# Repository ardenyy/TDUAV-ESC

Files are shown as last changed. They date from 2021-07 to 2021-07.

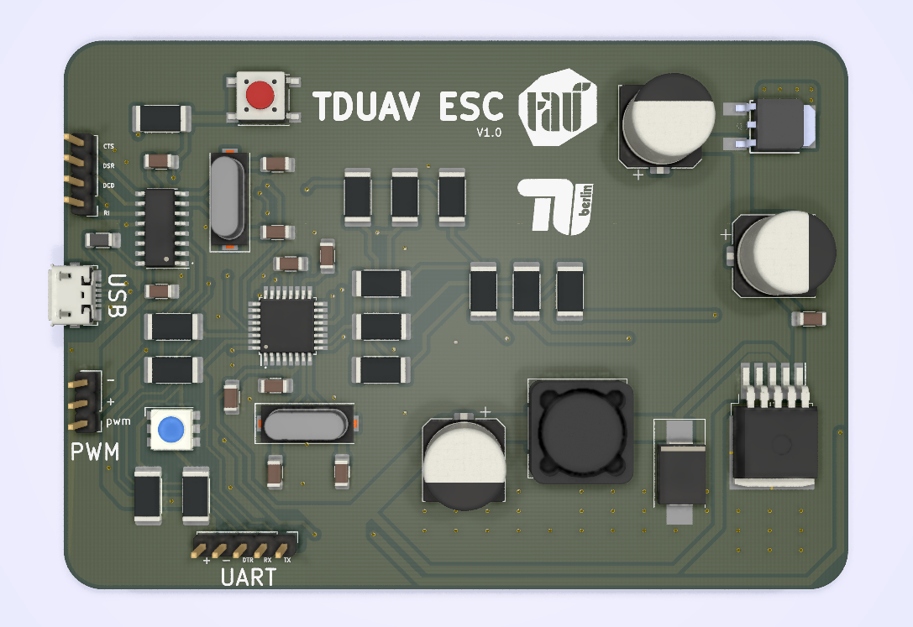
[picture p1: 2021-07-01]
Hardware/pcb_front.png

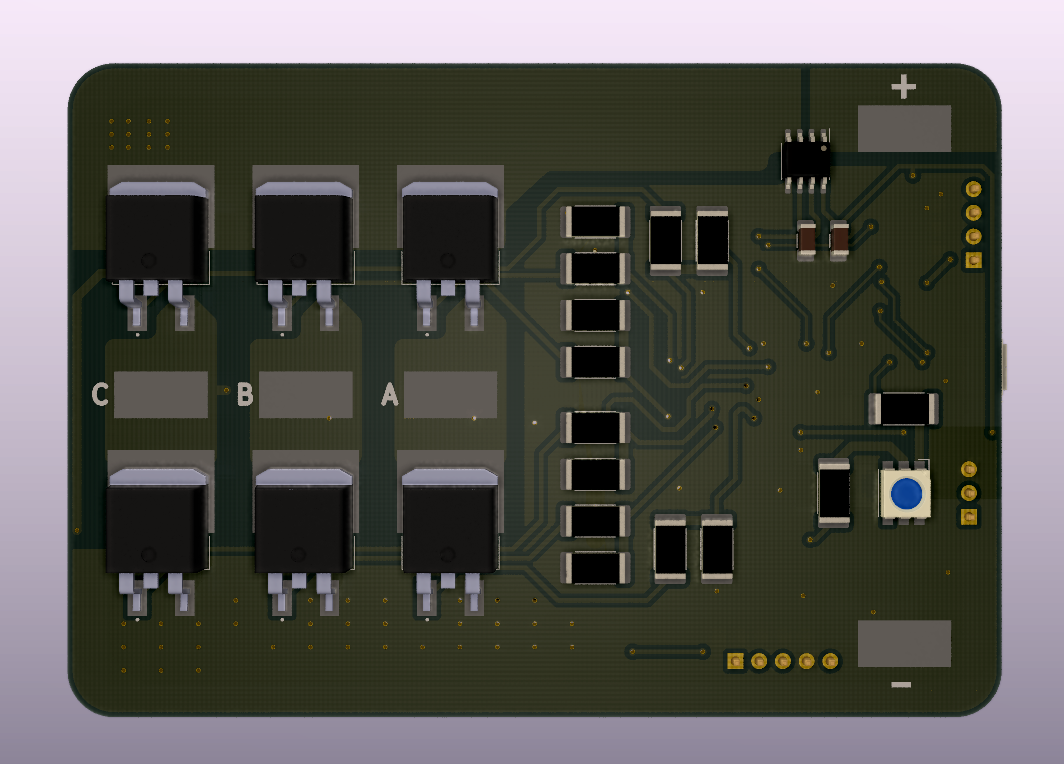
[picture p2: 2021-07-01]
Hardware/pcb_back.png

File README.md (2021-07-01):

# TDUAV-ESC
Electronic Speed Controller for BLDC Motors with 3A UBEC.

Made for UAV Team "**TDUAV**" at Turkish-German University.
- Atmega328P-AU Microcontroller
- Designed for 3S Li-Po Batteries
- BEMF Detection
- 5V/3A UBEC Circuit
- Up to 50A current sensing
- 35A Continuous, 50A Burst current output
- 100mm x 70mm

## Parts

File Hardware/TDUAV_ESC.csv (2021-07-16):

Source: | C:\Users\Ardeny\Documents\KiCAD\TDUAV_ESC\Hardware\TDUAV_ESC.sch
Date: | 17.07.2021 00:18:31
Tool: | Eeschema (5.1.9)-1
Component Count: | 73
Ref | Value | Footprint | Datasheet | Manufacturer | Vendor
C1 | 470uF | Capacitor_SMD:CP_Elec_10x10 | ~
C2 | 220uF | Capacitor_SMD:CP_Elec_10x10 | ~
C3 | 680nF | Capacitor_SMD:C_1206_3216Metric_Pad1.33x1.80mm_HandSolder | ~
C4 | 100nF | Capacitor_SMD:C_1206_3216Metric_Pad1.33x1.80mm_HandSolder | ~
C5 | 1nF | Capacitor_SMD:C_1206_3216Metric_Pad1.33x1.80mm_HandSolder | ~
C6 | 100nF | Capacitor_SMD:C_1206_3216Metric_Pad1.33x1.80mm_HandSolder | ~
C7 | 100nF | Capacitor_SMD:C_1206_3216Metric_Pad1.33x1.80mm_HandSolder | ~
C8 | 100nF | Capacitor_SMD:C_1206_3216Metric_Pad1.33x1.80mm_HandSolder | ~
C9 | 100nF | Capacitor_SMD:C_1206_3216Metric_Pad1.33x1.80mm_HandSolder | ~
C10 | 100nF | Capacitor_SMD:C_1206_3216Metric_Pad1.33x1.80mm_HandSolder | ~
C11 | 22pF | Capacitor_SMD:C_1206_3216Metric_Pad1.33x1.80mm_HandSolder | ~
C12 | 22pF | Capacitor_SMD:C_1206_3216Metric_Pad1.33x1.80mm_HandSolder | ~
C13 | 22pF | Capacitor_SMD:C_1206_3216Metric_Pad1.33x1.80mm_HandSolder | ~
C14 | 22pF | Capacitor_SMD:C_1206_3216Metric_Pad1.33x1.80mm_HandSolder | ~
C15 | 100nF | Capacitor_SMD:C_1206_3216Metric_Pad1.33x1.80mm_HandSolder | ~
C16 | 330uF | Capacitor_SMD:CP_Elec_10x10 | ~
C17 | 100nF | Capacitor_SMD:C_1206_3216Metric_Pad1.33x1.80mm_HandSolder | ~
D1 | SK56 | Diode_SMD:D_SMC_Handsoldering | ~
D2 | LED_RGB_5050 | LED_SMD:LED_RGB_5050-6
D3 | LED_RGB_5050 | LED_SMD:LED_RGB_5050-6
FB1 | 120R @ 100Mhz | Inductor_SMD:L_1206_3216Metric_Pad1.22x1.90mm_HandSolder | ~
J1 | USB_B_Micro | Connector_USB:USB_Micro-B_Molex_47346-0001 | ~
J2 | PWM-UBEC | Connector_PinHeader_2.54mm:PinHeader_1x03_P2.54mm_Vertical | ~
J3 | UART | Connector_PinHeader_2.54mm:PinHeader_1x05_P2.54mm_Vertical | ~
J4 | CH340 | Connector_PinHeader_2.54mm:PinHeader_1x04_P2.54mm_Vertical | ~
J5 | BATT | Connector_Wire:SolderWirePad_1x01_SMD_5x10mm | ~
J6 | GND | Connector_Wire:SolderWirePad_1x01_SMD_5x10mm | ~
J7 | PHASE_A | Connector_Wire:SolderWirePad_1x01_SMD_5x10mm | ~
J8 | PHASE_B | Connector_Wire:SolderWirePad_1x01_SMD_5x10mm | ~
J9 | PHASE_C | Connector_Wire:SolderWirePad_1x01_SMD_5x10mm | ~
L1 | 33uH | INDUCTOR_SMD:INDUCTOR_SMD_12X12X8 | ~
Q1 | IRLZ44NS | IRLZ44NSPBF:IRF2804STRLPBF | https://www.infineon.com/dgdl/irlz44nspbf.pdf?fileId=5546d462533600a40153567221272727
Q2 | IRLZ44NS | IRLZ44NSPBF:IRF2804STRLPBF | https://www.infineon.com/dgdl/irlz44nspbf.pdf?fileId=5546d462533600a40153567221272727
Q3 | IRFR9024 | IRFR9024:DPAK
Q4 | IRLZ44NS | IRLZ44NSPBF:IRF2804STRLPBF | https://www.infineon.com/dgdl/irlz44nspbf.pdf?fileId=5546d462533600a40153567221272727
Q5 | IRLZ44NS | IRLZ44NSPBF:IRF2804STRLPBF | https://www.infineon.com/dgdl/irlz44nspbf.pdf?fileId=5546d462533600a40153567221272727
Q6 | IRLZ44NS | IRLZ44NSPBF:IRF2804STRLPBF | https://www.infineon.com/dgdl/irlz44nspbf.pdf?fileId=5546d462533600a40153567221272727
Q7 | IRLZ44NS | IRLZ44NSPBF:IRF2804STRLPBF | https://www.infineon.com/dgdl/irlz44nspbf.pdf?fileId=5546d462533600a40153567221272727
R1 | 10KR | Resistor_SMD:R_2512_6332Metric_Pad1.40x3.35mm_HandSolder | ~
R2 | 1KR | Resistor_SMD:R_2512_6332Metric_Pad1.40x3.35mm_HandSolder | ~
R3 | 1KR | Resistor_SMD:R_2512_6332Metric_Pad1.40x3.35mm_HandSolder | ~
R4 | 1KR | Resistor_SMD:R_2512_6332Metric_Pad1.40x3.35mm_HandSolder | ~
R5 | 10KR | Resistor_SMD:R_2512_6332Metric_Pad1.40x3.35mm_HandSolder | ~
R6 | 1KR | Resistor_SMD:R_2512_6332Metric_Pad1.40x3.35mm_HandSolder | ~
R7 | 1KR | Resistor_SMD:R_2512_6332Metric_Pad1.40x3.35mm_HandSolder | ~
R8 | 150R | Resistor_SMD:R_2512_6332Metric_Pad1.40x3.35mm_HandSolder | ~
R9 | 2.2KR | Resistor_SMD:R_2512_6332Metric_Pad1.40x3.35mm_HandSolder | ~
R10 | 150R | Resistor_SMD:R_2512_6332Metric_Pad1.40x3.35mm_HandSolder | ~
R11 | 2.2KR | Resistor_SMD:R_2512_6332Metric_Pad1.40x3.35mm_HandSolder | ~
R12 | 33KR | Resistor_SMD:R_2512_6332Metric_Pad1.40x3.35mm_HandSolder | ~
R13 | 33KR | Resistor_SMD:R_2512_6332Metric_Pad1.40x3.35mm_HandSolder | ~
R14 | 33KR | Resistor_SMD:R_2512_6332Metric_Pad1.40x3.35mm_HandSolder | ~
R15 | 150R | Resistor_SMD:R_2512_6332Metric_Pad1.40x3.35mm_HandSolder | ~
R16 | 2.2KR | Resistor_SMD:R_2512_6332Metric_Pad1.40x3.35mm_HandSolder | ~
R17 | 150R | Resistor_SMD:R_2512_6332Metric_Pad1.40x3.35mm_HandSolder | ~
R18 | 2.2KR | Resistor_SMD:R_2512_6332Metric_Pad1.40x3.35mm_HandSolder | ~
R19 | 10KR | Resistor_SMD:R_2512_6332Metric_Pad1.40x3.35mm_HandSolder | ~
R20 | 10KR | Resistor_SMD:R_2512_6332Metric_Pad1.40x3.35mm_HandSolder | ~
R21 | 10KR | Resistor_SMD:R_2512_6332Metric_Pad1.40x3.35mm_HandSolder | ~
R22 | 33KR | Resistor_SMD:R_2512_6332Metric_Pad1.40x3.35mm_HandSolder | ~
R23 | 33KR | Resistor_SMD:R_2512_6332Metric_Pad1.40x3.35mm_HandSolder | ~
R24 | 33KR | Resistor_SMD:R_2512_6332Metric_Pad1.40x3.35mm_HandSolder | ~
R25 | 150R | Resistor_SMD:R_2512_6332Metric_Pad1.40x3.35mm_HandSolder | ~
R26 | 2.2KR | Resistor_SMD:R_2512_6332Metric_Pad1.40x3.35mm_HandSolder | ~
R27 | 150R | Resistor_SMD:R_2512_6332Metric_Pad1.40x3.35mm_HandSolder | ~
R28 | 2.2KR | Resistor_SMD:R_2512_6332Metric_Pad1.40x3.35mm_HandSolder | ~
SW1 | RESET_BUTTON | SW_PUSH_4:SW_PUSH_4_6X6mm_H3.1mm | ~
U1 | ATmega328P-AU | Package_QFP:TQFP-32_7x7mm_P0.8mm | http://ww1.microchip.com/downloads/en/DeviceDoc/ATmega328_P%20AVR%20MCU%20with%20picoPower%20Technology%20Data%20Sheet%2040001984A.pdf
U2 | ACS724-50A | Package_SO:SOIC-8_3.9x4.9mm_P1.27mm | http://www.allegromicro.com/~/media/Files/Datasheets/ACS724-Datasheet.ashx?la=en
U3 | LM2596S-5 | Package_TO_SOT_SMD:TO-263-5_TabPin3 | http://www.ti.com/lit/ds/symlink/lm2596.pdf
U4 | CH340G | Package_SO:SOIC-16_3.9x9.9mm_P1.27mm | http://www.datasheet5.com/pdf-local-2195953
Y1 | 16MHz | Crystal:Crystal_SMD_HC49-SD | ~
Y2 | 12MHz | Crystal:Crystal_SMD_HC49-SD | ~

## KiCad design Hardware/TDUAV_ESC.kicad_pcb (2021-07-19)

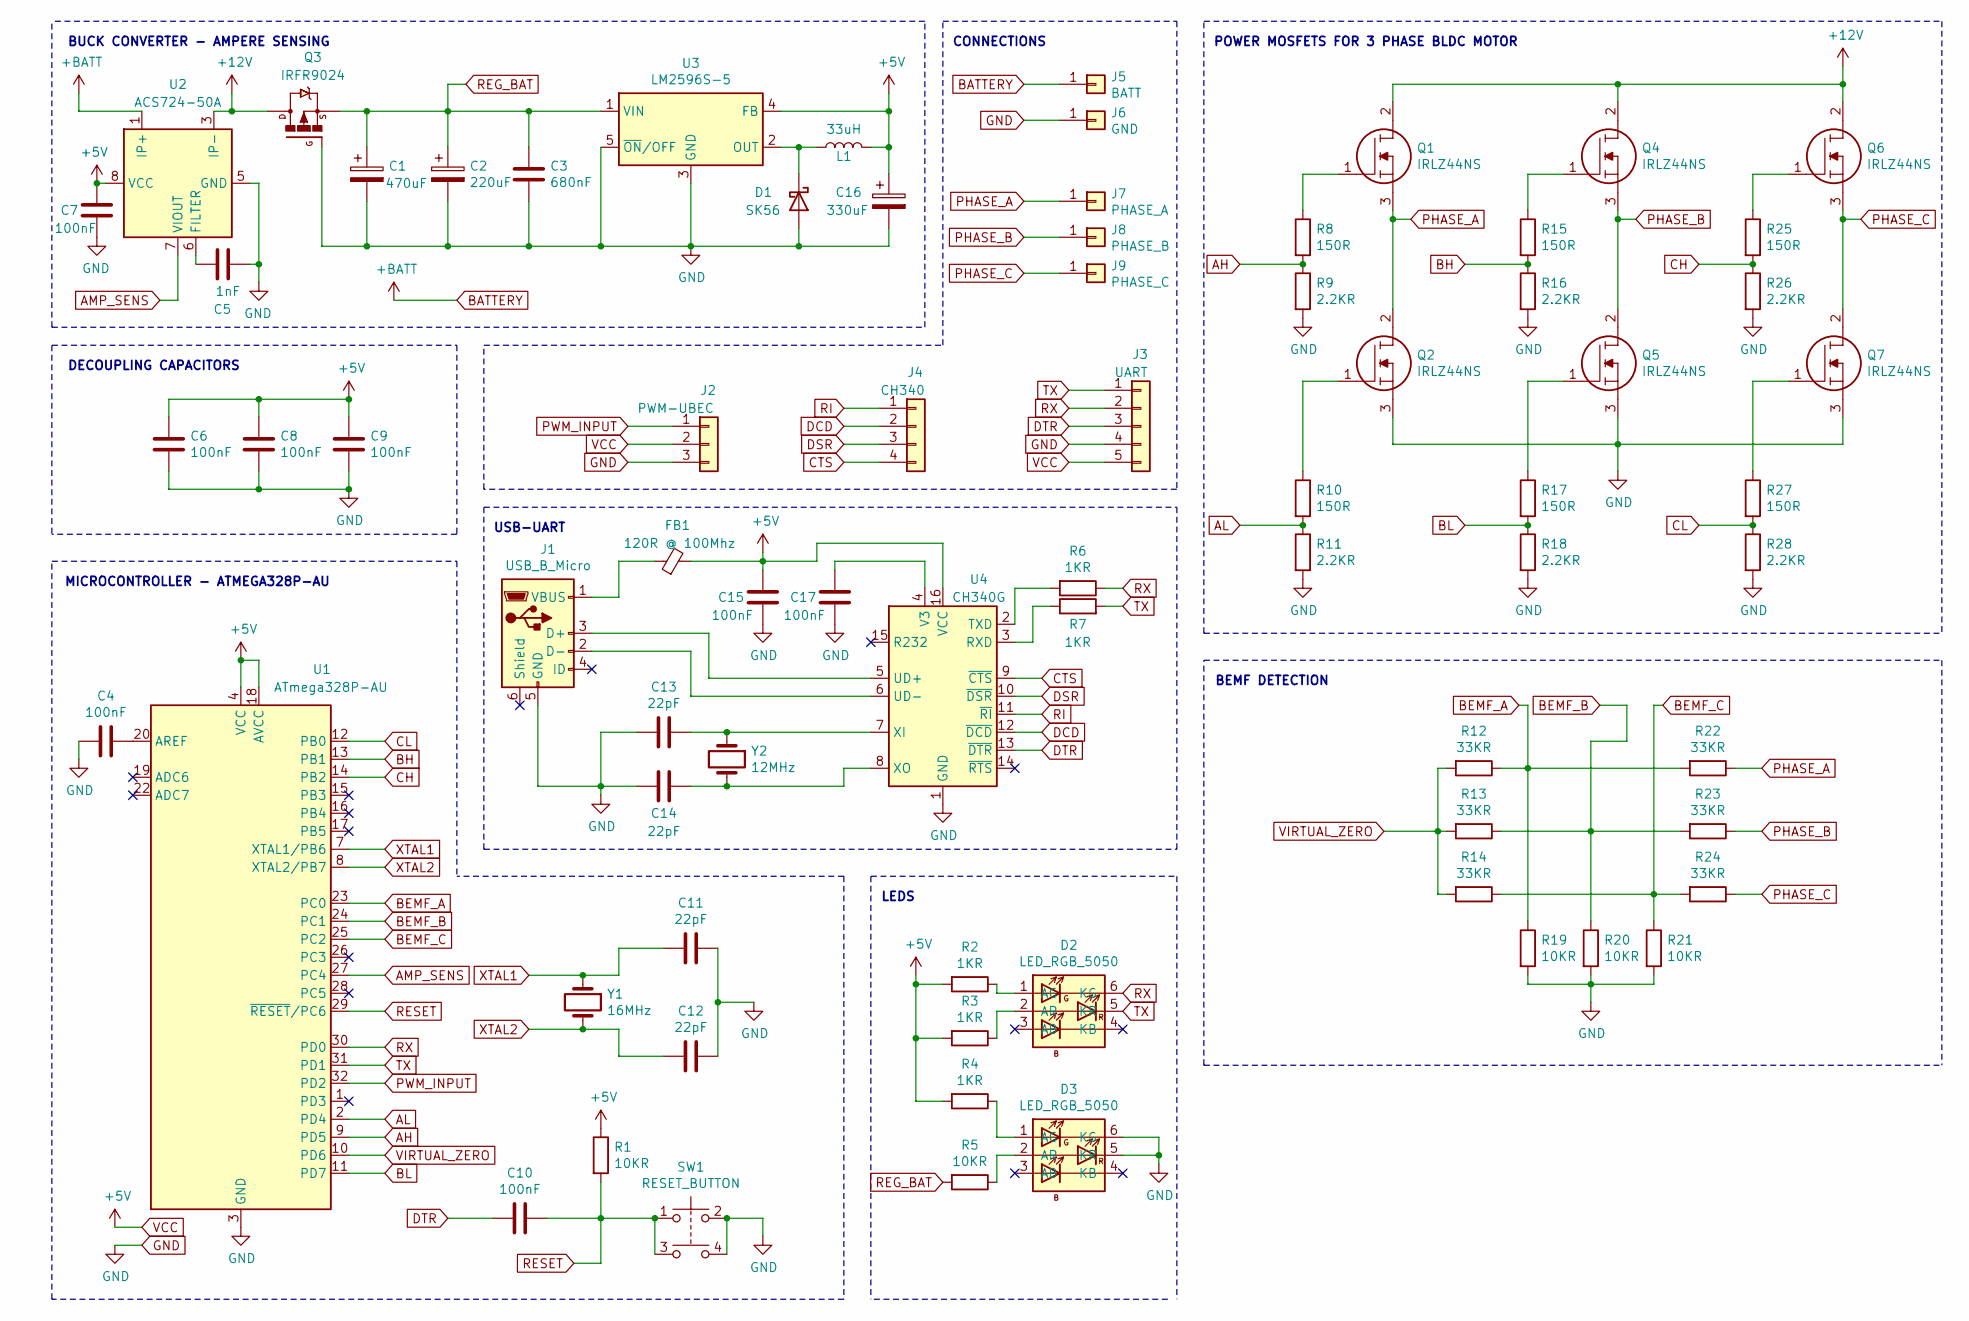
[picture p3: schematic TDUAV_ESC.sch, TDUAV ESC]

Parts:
C1: 470uF; CP_Elec_10x10
C2: 220uF; CP_Elec_10x10
C3: 680nF; C_1206_3216Metric_Pad1.33x1.80mm_HandSolder
C4, C6, C7, C8, C9, C10, C15, C17: 100nF; C_1206_3216Metric_Pad1.33x1.80mm_HandSolder
C5: 1nF; C_1206_3216Metric_Pad1.33x1.80mm_HandSolder
C11, C12, C13, C14: 22pF; C_1206_3216Metric_Pad1.33x1.80mm_HandSolder
C16: 330uF; CP_Elec_10x10
D1: SK56; D_SMC_Handsoldering
D2, D3: LED_RGB_5050; LED_RGB_5050-6
FB1: 120R @ 100Mhz; L_1206_3216Metric_Pad1.22x1.90mm_HandSolder
J1: USB_B_Micro; USB_Micro-B_Molex_47346-0001
J2: PWM-UBEC; PinHeader_1x03_P2.54mm_Vertical
J3: UART; PinHeader_1x05_P2.54mm_Vertical
J4: CH340; PinHeader_1x04_P2.54mm_Vertical
J5: BATT; SolderWirePad_1x01_SMD_5x10mm
J6: GND; SolderWirePad_1x01_SMD_5x10mm
J7: PHASE_A; SolderWirePad_1x01_SMD_5x10mm
J8: PHASE_B; SolderWirePad_1x01_SMD_5x10mm
J9: PHASE_C; SolderWirePad_1x01_SMD_5x10mm
L1: 33uH; INDUCTOR_SMD_12X12X8
Q1, Q2, Q4, Q5, Q6, Q7: IRLZ44NS; IRF2804STRLPBF; Manufacturer_Part_Number IRLZ44NSTRLPBF; Mouser Part Number 942-IRLZ44NSTRLPBF
Q3: IRFR9024; DPAK
R1, R5, R19, R20, R21: 10KR; R_2512_6332Metric_Pad1.40x3.35mm_HandSolder
R2, R3, R4, R6, R7: 1KR; R_2512_6332Metric_Pad1.40x3.35mm_HandSolder
R8, R10, R15, R17, R25, R27: 150R; R_2512_6332Metric_Pad1.40x3.35mm_HandSolder
R9, R11, R16, R18, R26, R28: 2.2KR; R_2512_6332Metric_Pad1.40x3.35mm_HandSolder
R12, R13, R14, R22, R23, R24: 33KR; R_2512_6332Metric_Pad1.40x3.35mm_HandSolder
SW1: RESET_BUTTON; SW_PUSH_4_6X6mm_H3.1mm
U1: ATmega328P-AU; TQFP-32_7x7mm_P0.8mm
U2: ACS724-50A; SOIC-8_3.9x4.9mm_P1.27mm
U3: LM2596S-5; TO-263-5_TabPin3
U4: CH340G; SOIC-16_3.9x9.9mm_P1.27mm
Y1: 16MHz; Crystal_SMD_HC49-SD
Y2: 12MHz; Crystal_SMD_HC49-SD

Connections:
+12V: Q1.2, Q3.4, Q4.2, Q6.2, U2.3 (IP-), U2.4 (IP-)
AH: R8.2, R9.1, U1.9 (PD5)
AL: R10.2, R11.1, U1.2 (PD4)
AMP_SENS: U1.27 (PC4), U2.7 (VIOUT)
BATTERY: J5.1, U2.1 (IP+), U2.2 (IP+)
BEMF_A: R12.1, R19.1, R22.2, U1.23 (PC0)
BEMF_B: R13.1, R20.1, R23.2, U1.24 (PC1)
BEMF_C: R14.1, R21.1, R24.2, U1.25 (PC2)
BH: R15.2, R16.1, U1.13 (PB1)
BL: R17.2, R18.1, U1.11 (PD7)
CH: R25.2, R26.1, U1.14 (PB2)
CL: R27.2, R28.1, U1.12 (PB0)
CTS: J4.4, U4.9 (~CTS)
DCD: J4.2, U4.12 (~DCD)
DSR: J4.3, U4.10 (~DSR)
DTR: C10.2, J3.3, U4.13 (~DTR)
GND: C1.2, C2.2, C3.2, C4.2, C5.2, C6.2, C7.2, C8.2, C9.2, C11.1, C12.1, C13.2, C14.2, C15.1, C16.2, C17.1, D1.2 (A), D3.5 (KR), D3.6 (KG), J1.5 (GND), J2.3, J3.4, J6.1, Q2.3, Q3.1, Q5.3, Q7.3, R9.2, R11.2, R16.2, R18.2, R19.2, R20.2, R21.2, R26.2, R28.2, SW1.2, SW1.4, U1.3 (GND), U1.5 (GND), U1.21 (GND), U2.5 (GND), U3.3 (GND), U3.5 (~ON~/OFF), U4.1 (GND)
unnamed: C4.1, U1.20 (AREF)
unnamed: C5.1, U2.6 (FILTER)
unnamed: C13.1, U4.7 (XI), Y2.1
unnamed: C14.1, U4.8 (XO), Y2.2
unnamed: C17.2, U4.4 (V3)
unnamed: D1.1 (K), L1.1, U3.2 (OUT)
unnamed: D2.1 (AG), R2.1
unnamed: D2.2 (AR), R3.1
unnamed: D3.1 (AG), R4.1
unnamed: D3.2 (AR), R5.1
unnamed: FB1.1, J1.1 (VBUS)
unnamed: J1.2 (D-), U4.6 (UD-)
unnamed: J1.3 (D+), U4.5 (UD+)
unnamed: Q1.1, R8.1
unnamed: Q2.1, R10.1
unnamed: Q4.1, R15.1
unnamed: Q5.1, R17.1
unnamed: Q6.1, R25.1
unnamed: Q7.1, R27.1
unnamed: R6.2, U4.2 (TXD)
unnamed: R7.1, U4.3 (RXD)
PHASE_A: J7.1, Q1.3, Q2.2, R22.1
PHASE_B: J8.1, Q4.3, Q5.2, R23.1
PHASE_C: J9.1, Q6.3, Q7.2, R24.1
PWM_INPUT: J2.1, U1.32 (PD2)
REG_BAT: C1.1, C2.1, C3.1, Q3.3, R5.2, U3.1 (VIN)
RESET: C10.1, R1.2, SW1.1, SW1.3, U1.29 (~RESET~/PC6)
RI: J4.1, U4.11 (~RI)
RX: D2.6 (KG), J3.2, R6.1, U1.30 (PD0)
TX: D2.5 (KR), J3.1, R7.2, U1.31 (PD1)
VCC: C6.1, C7.1, C8.1, C9.1, C15.2, C16.1, FB1.2, J2.2, J3.5, L1.2, R1.1, R2.2, R3.2, R4.2, U1.4 (VCC), U1.6 (VCC), U1.18 (AVCC), U2.8 (VCC), U3.4 (FB), U4.16 (VCC)
VIRTUAL_ZERO: R12.2, R13.2, R14.2, U1.10 (PD6)
XTAL1: C11.2, U1.7 (XTAL1/PB6), Y1.1
XTAL2: C12.2, U1.8 (XTAL2/PB7), Y1.2

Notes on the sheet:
BUCK CONVERTER - AMPERE SENSING
DECOUPLING CAPACITORS
LEDS
USB-UART
BEMF DETECTION
MICROCONTROLLER - ATMEGA328P-AU
POWER MOSFETS FOR 3 PHASE BLDC MOTOR
CONNECTIONS

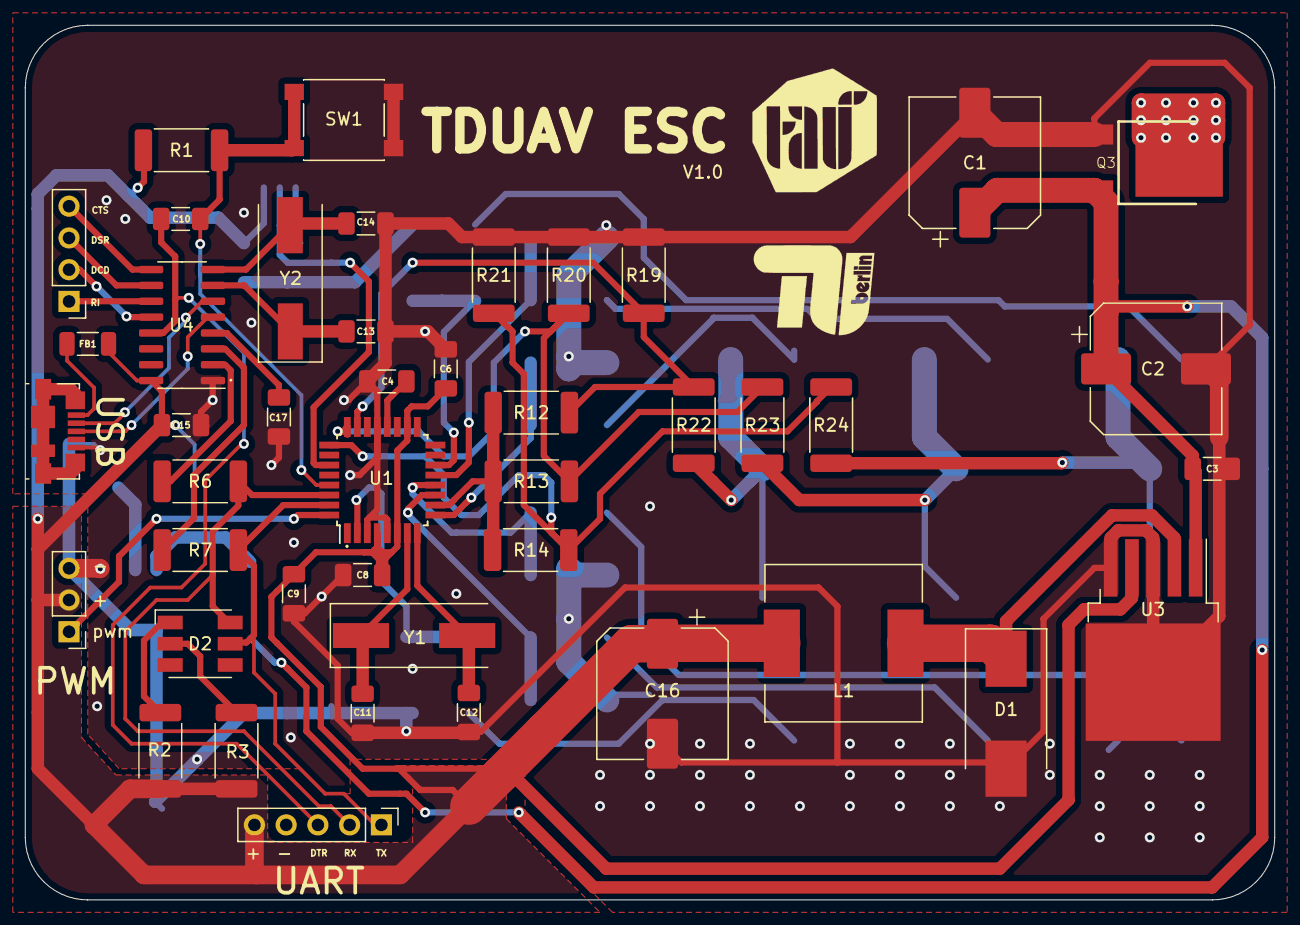
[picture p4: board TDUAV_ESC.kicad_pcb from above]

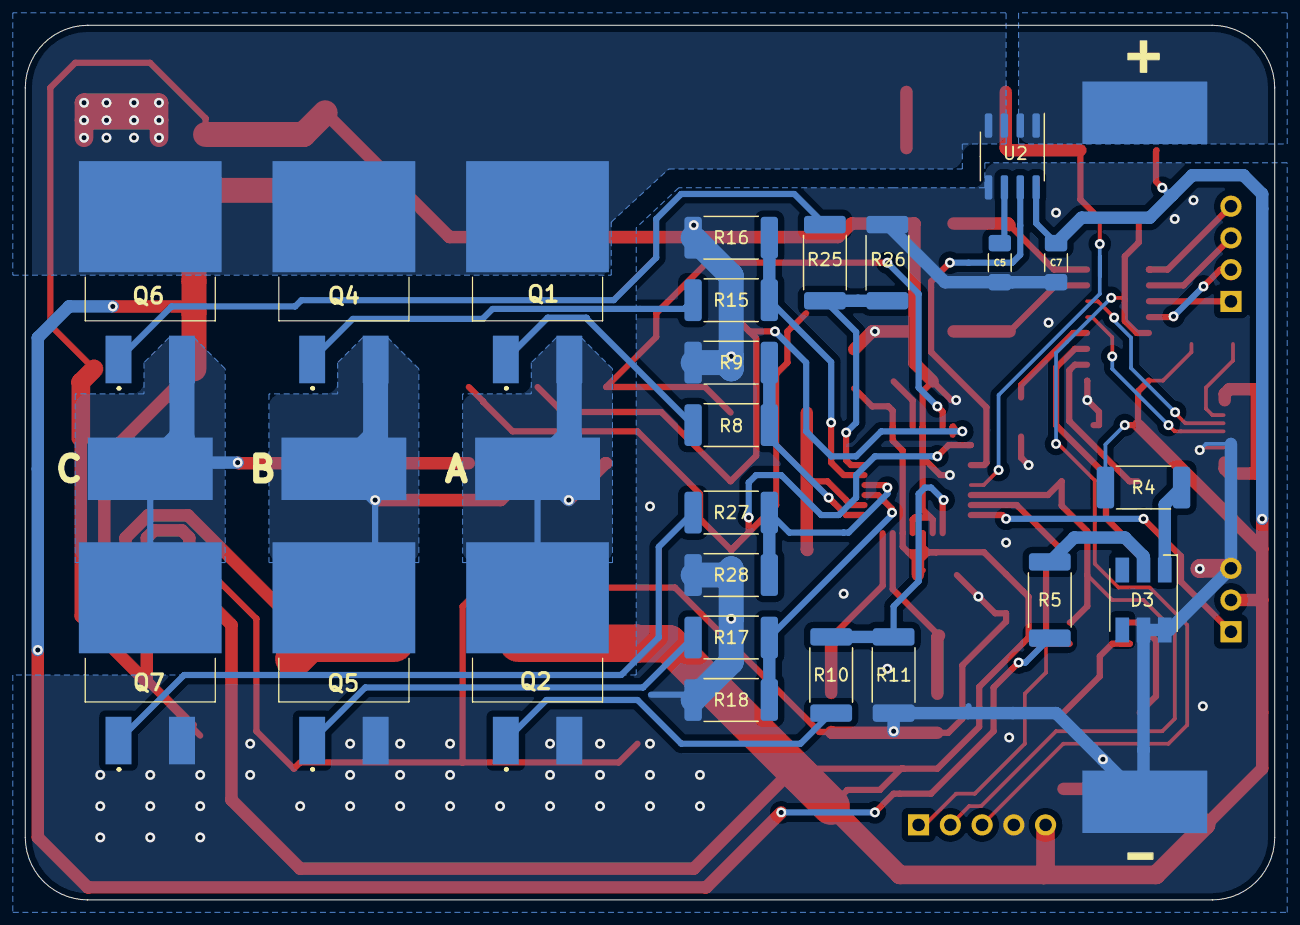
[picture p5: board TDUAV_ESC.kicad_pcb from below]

Board: 2 copper layers, 100.0 x 70.0 mm, 73 parts (29 on the bottom side), 51 nets.

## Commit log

2021-06-24 Added PCB images for preview
2021-06-29 Edited Silkscreens
    [TDUAV_ESC.kicad_pcb]
2021-07-01 Updated PCB 3D Images
2021-07-16 Added cap to ch340 and changed values of decoupling caps
    [TDUAV_ESC.csv, TDUAV_ESC.kicad_pcb, TDUAV_ESC.sch]
2021-07-19 Updated PCB design
    [TDUAV_ESC.kicad_pcb]
